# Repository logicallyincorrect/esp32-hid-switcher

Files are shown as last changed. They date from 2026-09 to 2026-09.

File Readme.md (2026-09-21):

# HID Switcher

HID Switcher — one keyboard and mouse, three computers

Use one USB keyboard and mouse with up to three Bluetooth-enabled computers.

Only the selected computer receives input. The other Bluetooth connections stay open. Names, pairings, and shortcuts stay in memory after a restart.

## Hardware

- Freenove ESP32-S3: 16 MB flash and 8 MB PSRAM.
- USB keyboard and relative HID mouse.
- USB hub, if you connect both devices.

Connect the hub to the native USB/OTG port. Use the UART/COM port for power and firmware installation. Use a powered hub if the board cannot supply sufficient power.

A CH340 USB-to-UART port cannot operate as a USB host.

An optional [BLE keyboard/trackpad input experiment](docs/ble-input.md) adds one wireless input peripheral alongside USB, using a separate four-connection build. It is not enabled in the normal firmware.

Printable case files, measured board dimensions, and assembly instructions are in [stls](stls/README.md).

For a print-ready folded handout, use the two-page [A4 quick-start sheet](docs/quick-start-a4.html) (print landscape, duplex, short-edge binding).

## Install or update

Identify the correct board and UART port before installation. Use PlatformIO with [platformio.ini](platformio.ini).

```sh
pio run -e esp32s3_usb_ble_absolute
pio device list
pio run -e esp32s3_usb_ble_absolute -t upload --upload-port YOUR_UART_PORT
```

These commands install the companion-free absolute-pointer build. Use `-e esp32s3_usb_ble` instead for relative-only firmware with optional macOS companion routing. The `esp32s3_usb_ble_absolute_only` environment is a diagnostic fallback, not the full calibration-capable firmware.

All firmware updates use USB. The [browser setup page and serial CLI](docs/usb-setup.md) can configure the device over its UART/programming port, including first-time BLE keyboard pairing without an existing keyboard. The BOOT menu remains available; no Wi-Fi is needed. The existing partition layout remains compatible with saved settings. Do not erase flash unless you want to remove pairings and settings.

## Connect computers

1. Press Ctrl + Cmd + 1.
2. Pair **HID SWITCHER BLE** in the first computer's Bluetooth settings.
3. Press Ctrl + Cmd + 2.
4. Pair the second computer.
5. Repeat for slot 3, if necessary.

Cmd means Command on macOS or Windows/Super on other keyboards. Left and right modifier keys have the same function.

## Switch at the edge of the screen

Both options provide seamless edge switching, **off by default**. Choose the firmware for the behavior you want:

| | Companion-free mode | macOS companion mode |
| --- | --- | --- |
| Firmware environment | `esp32s3_usb_ble_absolute` | `esp32s3_usb_ble` |
| Software on each computer | None | macOS companion on each source Mac |
| Pointer output | Absolute when enabled; relative otherwise | Relative |
| Setup | Enable in menu; calibrate each slot or choose All | Install companion, then enable in menu |
| Screen information | Two-corner calibration, one display per computer | Companion reports desktop edges; shared monitor boundaries stay on the same computer |
| Pointer after switching | Opposite edge, retaining normalized vertical position | Destination pointer stays where it was |
| Mouse controls | Five buttons and vertical scroll in absolute mode | Eight buttons and horizontal/vertical scroll |

Both use slots 1 → 2 → 3 from left to right, skip disconnected computers, and do not wrap at an outer edge. Dragging, held keys and configuration block automatic switching. Keyboard/mouse switching shortcuts work in either mode.

For companion-free mode, select **6 Seamless switching → 1 Enable**. Missing calibration starts the two-corner procedure before switching can turn on. Recalibrate one slot or all connected computers through **6 → 3 Calibrate pointer**. The integrated build works on both tested computers, including absolute dragging. See [calibration instructions and limitations](docs/absolute-pointer.md).

Download the companion ZIP from [Releases](https://github.com/logicallyincorrect/esp32-hid-switcher/releases), or get a development build from [Actions](https://github.com/logicallyincorrect/esp32-hid-switcher/actions/workflows/companion-macos.yml). See [build and installation instructions](companion/README.md).

An optional [macOS companion](companion/README.md) lets you push the pointer against the right edge to select the next computer, or the left edge to select the previous one. Install it on each Mac from which you want to switch at a screen edge. Disconnected computers are skipped. Slots run left to right as 1, 2, 3. Edge switching stops at either end and does not wrap. Switching does not require a companion on the destination. Push outward after reaching an edge to switch input (100 mouse counts by default); the destination pointer stays where it was.

Shared monitor boundaries stay on the same computer. Dragging, held keys, and the setup menu disable edge switching. Keyboard and mouse shortcuts remain available.

The normal build requires the companion, updated firmware, and **6 Seamless switching → 1 Enable**. Hardware validation is pending.

## Configure the device

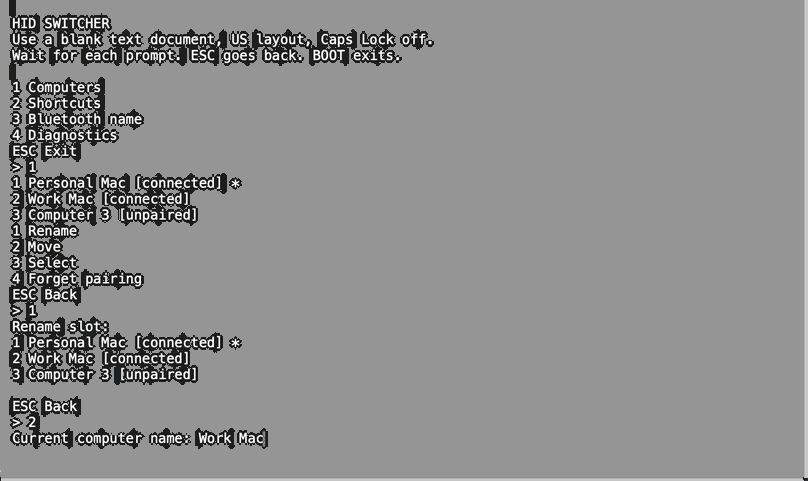
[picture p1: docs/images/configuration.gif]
Streaming device configuration in a text editor


1. Open a blank document in a text editor on the selected computer.
2. Select the US keyboard layout on that computer.
3. Set Caps Lock to off.
4. Hold BOOT for three seconds.
5. Wait for the menu and its `>` prompt.
6. Press a menu number.

The device types the menu into the document. It reads configuration input directly from the attached USB keyboard and mouse. No software installation is necessary.

Use a text editor, not a command shell. Keep the document selected until you exit. The device cannot detect which application receives its text.

| Menu | Function |
| --- | --- |
| Computers | Rename, move, select, or forget a computer |
| Shortcuts | Record, clear, or restore shortcuts |
| Bluetooth name | Change the device name |
| Diagnostics | Show USB status, Bluetooth errors, and report times |
| Edge switching | Set the outward movement distance (1-10000 counts) |
| Seamless switching | Opt in/out; calibrate one slot or All in the absolute build |
| Pointer tuning | Advanced per-computer axis percentages (absolute build) |
| BLE input devices | Scan, select, pair, reconnect, disconnect, or forget a wireless keyboard/trackpad (experimental BLE input build) |

To change the edge distance, select **5 Edge switching**, enter a value, press Enter, then `y`. The value applies immediately and stays saved after restart.

Each configuration menu shows the current settings. Unassigned shortcuts show **Not set**.

Enter names with printable ASCII characters. Press Enter to review a name. Press `y` to save or `n` to cancel. Uppercase `Y` and `N` also work.

Press Escape to go back without saving the current input. Escape at the main menu exits setup. Press BOOT to exit from any screen. The menu also closes after two minutes without input or if its Bluetooth connection is lost. Selecting another computer closes the menu before the switch.

The RGB LED is yellow in configuration mode. Normal keyboard and mouse input stops while the menu is open.

## Shortcuts

| Action | Function | Default | Input device |
| --- | --- | --- | --- |
| Cycle | Next connected computer | Ctrl + Cmd + Tab | Keyboard, mouse, or both |
| Next | Next connected computer | None | Keyboard, mouse, or both |
| Previous | Previous connected computer | None | Keyboard, mouse, or both |
| Slot | Any slot, including disconnected slots | Ctrl + Cmd + 1/2/3 | Keyboard only |

Cycle, Next, and Previous skip disconnected computers and repeat through the slot list. With no other connected computer, selection stays unchanged.

To change a shortcut:

1. Select **Shortcuts** from the menu.
2. Select the action.
3. Select **Record**.
4. Wait for the prompt.
5. Press and release the combination on the attached USB keyboard or mouse.
6. Press `y` to save after the confirmation prompt.

For Slot, record only modifier keys. Use those keys with 1, 2, or 3 to select a slot. Mouse shortcuts can include keyboard modifiers. Wheel and movement gestures are not supported.

**Clear keyboard** and **Clear mouse** remove only the specified input type. Recording one input type keeps the other shortcut. **Restore defaults** resets all shortcuts. Each change requires confirmation.

## Forget a pairing

1. Select **Computers**, then **Forget pairing**.
2. Select the computer's slot.
3. Check the displayed name.
4. Press `y` or `Y` to confirm.

The bridge disconnects that computer and clears its pairing. The slot name, shortcuts, and other pairings stay saved. If you forget the current computer, setup closes when it disconnects. Press Esc or `n` to cancel before removal.

Also forget HID SWITCHER BLE in that computer's Bluetooth settings before pairing again. Select the empty slot to pair a replacement computer.

## Status and recovery

GPIO2 flashes the selected slot number. The RGB LED shows blue/green/purple for slots 1/2/3. A steady light means ready; a flashing light means disconnected.

Initial pairing does not require the menu. Use the default Slot shortcut to select an empty slot. If Bluetooth is unavailable, use UART at 115200 baud: `1`/`2`/`3` selects a slot, `?` shows status, `u` restarts USB devices, and `v` toggles verbose USB diagnostics (off by default).

## Limits and tests

Tested hardware: Moonlander, Logitech MX Master 3S receiver, USB hub, and two Macs. Three simultaneous computers and other operating systems require more tests.

Connect your keyboard and mouse directly or through one USB hub. Hubs cannot be chained together. Keyboards must support sending up to six held keys at once, plus modifier keys such as Ctrl and Shift. Relative mode supports eight mouse buttons and horizontal/vertical scrolling. Absolute mode currently supports five mouse buttons and vertical scrolling.

Media keys, touchscreens, and drawing tablets are not supported. Vendor-specific configuration protocols, including HID++, are not supported yet.

Menu text requires the US keyboard layout and Caps Lock off. Normal input does not have this restriction. Diagnostics do not measure total mouse-to-screen delay.

```sh
sh scripts/test-host.sh
pio run -e esp32s3_usb_ble -e esp32s3_usb_ble_absolute
python3 tests/partition-layout.py
```

Host tests cover menu commands, output flow, shortcuts, and input routing. They do not replace tests with physical devices.

See [architecture](docs/architecture.md), [dependencies](DEPENDENCIES.md), and [planned work](TODO.md).

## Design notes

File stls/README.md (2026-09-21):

# Freenove ESP32-S3 snap-fit case

Printable prototype for the user's measured 16 MB, no-camera Freenove board with soldered headers. Two parts: a base and a lid with integral BOOT/RESET flexures, downward actuator pegs, four releasable short snap catches behind the buttons. Outside dimensions: **38 × 64.95 × 24.9 mm**. All snap teeth are inside this outline.

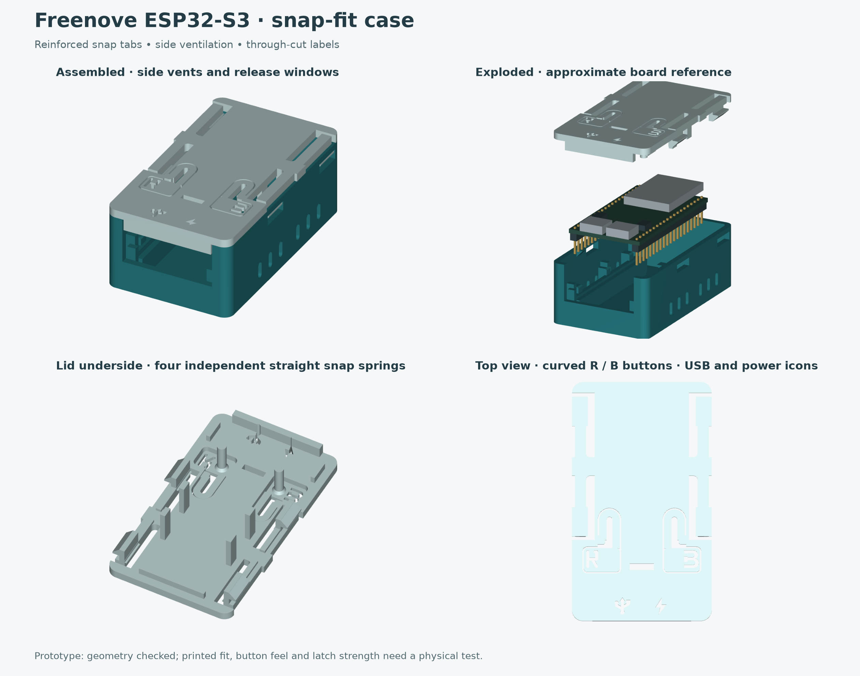
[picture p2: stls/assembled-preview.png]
Assembly and underside


## Ventilation and cut-through labels

Twelve vertical rounded **2 × 5 mm** ventilation slots form matching patterns on the lower side walls, six per side. They remain exposed when a hub covers the lid. The slot bottoms are 3.5 mm above the underside; they do not cut the snap pockets or roots. Thermal performance has not been measured.

**R** and a rounded **B** are straight through-cut stencil letters on the moving button tabs, on the outboard part of each rounded paddle at Y=12.8 mm, clear of the actuator peg roots. The B uses two 0.8 mm bridges across its left stem to retain the centres while preserving its rounded lobes.

A **USB trident** identifies the left native USB/OTG connector; a **lightning bolt** identifies the right UART/power/programming connector, viewed with the USB ports toward you. This mapping follows the UART connection illustration on printed page 28 (PDF page 30) of [Freenove's C tutorial](https://github.com/Freenove/Freenove_ESP32_S3_WROOM_Board_Lite/blob/main/C/C_Tutorial.pdf). Both icons are straight through-cuts over their ports, replacing HUB/PWR text.

There is no raised, bevelled or shallow engraved text. The cutouts stay within the button tabs; the surrounding U slots and peg roots remain intact. Clear strings from the apertures after printing. Letter cutouts change the tabs' stiffness, so button feel and fatigue need a physical check.

## Internal snap-fit revision

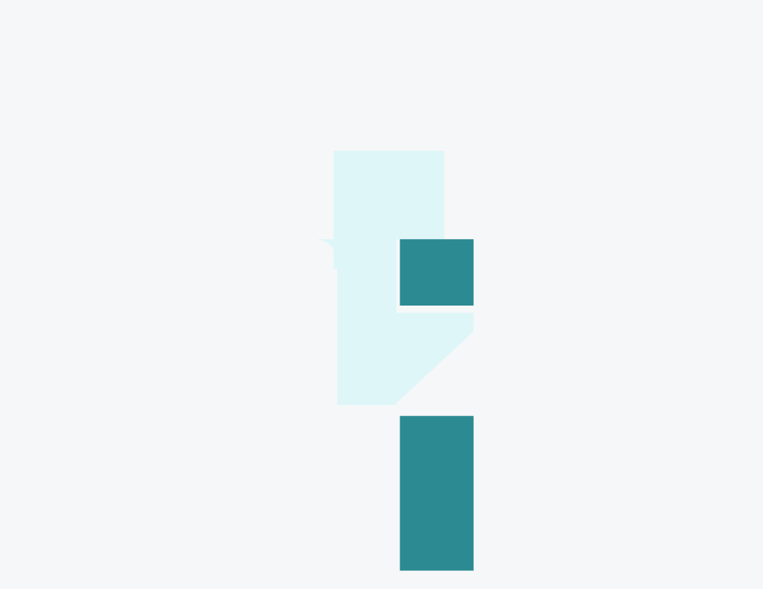
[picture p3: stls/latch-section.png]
Actual latch cross-section: light lid tongue beneath dark base shoulder


The previous tall tongues broke almost immediately in the user's PLA print. They are replaced by **four short, solid internal catches**, two per side at Y=23 and 53 mm: **4.5 mm projection** instead of 10 mm, **8 mm width**, **1.6 mm constant thickness**, and **0.6 mm root fillets**. The teeth overlap the base by **2.0 mm**, increased by 0.5 mm from the preceding version. Flat retaining shoulders sit 0.2 mm below the catch roofs. The teeth now reach the outside wall plane through the existing catch windows.

Each tooth now has its **own straight spring**, two per side, replacing the U-return shape. Each spring is now **3.0 mm wide** (previously 1.6 mm), with a **16.5 mm free length**, **1.2 mm plan-view root fillet**, and a **1.6 mm wide × 0.8 mm deep underside reinforcing rib**. The rib sits inside the base wall and increases the local section depth from 2.4 to 3.2 mm. This revision targets infrequent opening and firmer lid retention, rather than an easy-release feel. Front and rear springs attach independently to rigid roof near the middle of each side. The four teeth extend 0.5 mm farther outward into the existing windows, with 2.4 mm inward relief for 2.2 mm release movement. The R/B button springs retain their curves.

CAD verifies four separate spring attachments and nominal catch clearance, not printed stiffness or fatigue. A temporary root-severing check detaches four separate spring-and-tooth pieces.

**This stiffness revision needs only a new lid.** The base and R/B buttons are unchanged; the snap springs are reinforced and the four teeth extend 0.5 mm farther outward. All zip-tie slots have been removed, leaving solid roof around the spring roots. The base has four **9 × 3 mm** through catch windows near the seam. The rear pair remains at Y=53 mm. Push the teeth inward through these windows while lifting evenly.

Optional `snap-test-base.stl` and `snap-test-lid.stl` are cropped mating sections for checking insertion, tooth return and release before another full print. They preserve the latch geometry and print orientations but do not reproduce complete-case stiffness or hub loads. Do not infer full-case strength from the coupons.

Both header channels and their housing guides move **0.55 mm outward per side** after the latest printed fit showed the channels were 1 mm too close together. Their modelled centre spacing is now **24.5 mm**, increased from 23.4 mm. This uses the latest approximate 24.5 mm measurement, interpreted as row centre-to-centre spacing. Fore-and-aft clearance is now 0.1 mm total (0.05 mm per end), down from 0.3 mm. The end stops extend up to the PCB edges rather than locating only the assumed header-plastic ends. This closer fit needs a physical check; do not force the PCB if print tolerances close the gap. Side locators allow 0.15 mm per side. Tapered guide ribs locate the Dupont plastic housing; the 1.2 mm pin channels leave clearance around the metal contacts. This is a close sliding fit, not an intentional interference fit that bends pins. Header plastic width is still modelled as 2.54 mm.

The prior PLA improvements remain: 1.6 mm bearing rails/end fences, substantial lid hold-down ribs (now 1.5 × 3.2 mm, repositioned for the moved headers), 2.6 mm pegs, rounded slot ends, and 45-degree button-stop ramps in the base. Each button now has a shorter 2.0 mm thick U-return spring with 2.0 mm legs and 2.8 / 0.8 mm outer / inner bend radii. The bend moves forward 4 mm to Y=23.5 mm. The surrounding cutout follows the rounded paddle and rounded spring end with 0.4 mm perimeter clearance, replacing the large rectangular opening, joining a rounded paddle. The side root is rounded and thickened to match. The paddles remain 1.2 mm thick so their stop contact stays unchanged. The peg centres, rest gaps and supported travel stops remain unchanged. Printed fit, button force and repeated latching need another prototype.

## Files

- `base.stl`: print flat bottom down, as exported.
- `lid.stl`: print flat exterior face down, pegs/hooks pointing up, as exported.
- `case.step`: editable assembled case geometry.
- `board-reference.step`: approximate clearance reference, not a printable case part.
- `board.json`, `generate.py`, `preview.py`: measured inputs, parametric CAD and actual-geometry renderer.
- `validation.json`: solid, mesh, assembly, insertion and clearance checks.
- `slicer-validation.json`: Bambu Studio slicing smoke-check result and input hashes.

## Measurements and allowances

User caliper measurements are recorded in `board.json`. X measurements start at the left PCB edge, with USB ports toward the viewer. CAD X=0 is the board centreline. Y=0 is the USB-end PCB edge, not the connector face. See [measurement diagram](measurements.svg).

| Feature | Nominal allowance |
| --- | --- |
| Main PCB location | 0.15 mm each side; 0.05 mm each end |
| Pin tips above floor | 1.15 mm |
| Pin channel | 1.2 mm wide for a measured 0.65 mm pin (0.275 mm clearance per side) |
| Board vertical retention | 0.25 mm above PCB at hold-downs |
| Button peg rest gap | 0.5 mm above unpressed switch |
| Button flexure | Short U-return, 2.0 mm thick, 2.0 mm legs; 1.2 mm paddle |
| Button travel stop | Base wall ramp under outer paddle, 1.2 mm tab travel; switch travel itself is unmeasured |
| Lid locating lips | 0.3 mm from inner wall |
| Snap hooks | 2.0 mm engagement, entry ramp, internal catches and inward release |

A common 27.6 × 10.2 mm opening accommodates both USB connectors and cable overmoulds. Cable overmoulds were not measured; check your actual plugs. USB centres, shell widths/heights and zero protrusion use the supplied measurements. USB shell depth and module footprint remain approximate; overall component height uses the supplied 3 mm maximum (USB shell separately 3.1 mm).

## Printing and assembly

This revision targets PLA. Use your calibrated PLA profile; printed PLA still has limited flexure fatigue life. Suggested starting settings: 0.4 mm nozzle, 0.2 mm layers, 4 walls, 5 top/bottom layers, 20–30% infill. These are prototype settings, not mechanically validated. Preserve the exported orientations and print at 100% scale.

The base cable opening is open at the top, avoiding a long bridge. The button stops are now supported 45-degree base ramps, not lid bridges.  Avoid supports in the button slots. Keep seams off flexure roots and snap ramps where practical.

1. Remove strings and elephant-foot burrs, especially around the button and snap reliefs.
2. Check that the four spring reliefs are free of strings.
3. Drop the board into the base, USB ports at the opening. Header plastic rests on the rails; pins sit in the channels. The header centres are now 24.5 mm apart based on the approximate measurement; do not force the board if it does not seat.
4. Lower the lid squarely and engage all four catches. Confirm both buttons are released at rest and can be pressed individually. Trim pegs slightly if the switches are preloaded; regenerate longer pegs if they cannot reach. Stop if button force rises sharply.
5. Gently move each internal tooth inward about 2.2 mm through its release window, then lift the lid. Lift evenly rather than pulling hard on a single corner.

## Verification

Both STL meshes are watertight, consistently wound, single connected parts on Z=0. The CAD checks found no interference between the assembled case and nominal board envelopes, through the board's vertical insertion path, or at sampled ±0.14 mm X and ±0.04 mm Y board offsets. Retaining-shoulder probes catch after 0.35 mm of upward movement and clear the wall after 2.2 mm inward release. The shoulders also catch with 0.4 mm of simulated engagement loss. These are geometry checks, not a spring simulation. These checks cover the modelled geometry, not unknown components, cable bodies or material deformation.

Bambu Studio 02.08.02.61 successfully sliced both case STLs and both snap-test coupons on one X1 Carbon 0.4 mm plate at 0.2 mm layers, using four walls, 25% infill, five top/bottom layers, supports disabled, and the Generic PLA preset. The CLI returned success with no warnings. This is a slicing smoke check, not a physical bridging/strength test. No printer was contacted. Generated G-code is not distributed; slice for your own printer and filament.

The user physically tested the preceding internal-snap version and reported that the tall teeth broke almost immediately. This revised version has not been physically tested; latch strength, tooth return, closer housing fit remain to be checked.

## Regenerate

```sh
uv venv /tmp/hid-case-cad-venv --python 3.11
uv pip install --python /tmp/hid-case-cad-venv/bin/python -r stls/requirements.txt
/tmp/hid-case-cad-venv/bin/python stls/generate.py
/tmp/hid-case-cad-venv/bin/python stls/preview.py
```

The generator stages its outputs and publishes only after all geometry checks pass. Re-run slicing after any geometry change; `slicer-validation.json` records hashes to identify the exact checked STLs.

## References

User caliper measurements supersede photo estimates. [Manufacturer listing](https://store.freenove.com/products/fnk0099) and [pinout](https://github.com/Freenove/Freenove_ESP32_S3_WROOM_Board_Lite/blob/main/ESP32S3_Lite_Pinout.png) identify the layout. The [user-supplied MakerWorld mockups](https://makerworld.com/en/models/1625563-freenove-esp32-s3-wroom-model-files#profileId-1716334) include the Lite variant; their author adds component and GPIO clearance. The listing was inspected, but its mesh was not imported or redistributed. The approximate board reference here is built independently from measurements and simple envelopes.

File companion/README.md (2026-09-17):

# Edge-switching companion

The optional macOS companion switches computers when you push the pointer against the left or right edge of your desktop. Right selects the next available slot; left selects the previous slot. It skips disconnected computers. Slots run left to right as 1, 2, 3. Edge switching stops at either end and does not wrap. The destination does not need a companion.

Install it on each Mac from which you want to switch at a screen edge. It requires macOS 13 or later, Bluetooth, Accessibility permission, and firmware with the edge service. Pair HID Switcher in macOS Bluetooth settings first. Existing shortcuts and device configuration work without this companion. No Wi-Fi or network listener is used.

## Download

Published [GitHub releases](https://github.com/logicallyincorrect/esp32-hid-switcher/releases) include `HID-Switcher-Companion-macOS.zip` and its SHA-256 checksum after the build succeeds. The ZIP supports Intel and Apple Silicon Macs on macOS 13 or later.

For a development build, open [Actions → macOS companion](https://github.com/logicallyincorrect/esp32-hid-switcher/actions/workflows/companion-macos.yml), select a successful run, and download its artifact. Extract the artifact, then extract the app ZIP inside it. Artifacts expire after 30 days.

## Automated builds

The workflow tests and builds companion changes on pull requests and pushes to `main`. To build manually, open the workflow page, select **Run workflow**, and choose a branch.

Publishing a GitHub release builds that release's tag and attaches the ZIP and checksum. A failed build uploads no release assets. Re-running a successful release workflow replaces those two assets. Tags alone do not create a release.

Builds use an ad-hoc signature. They are not Apple-notarized and require no signing secrets. CI checks tests, both CPU architectures, the extracted app, executable permissions, and signature integrity. It does not test Bluetooth hardware or Gatekeeper approval.

## Open the app

Copy `HID-Switcher-Companion-macOS.zip` to the other Mac and unzip it. Move the complete `HID Switcher Companion.app` to Applications, then double-click it. The app supports Intel and Apple Silicon Macs; do not copy only the executable from inside the bundle. A mouse icon appears in the macOS menu bar. Open its menu, select **Choose device**, and select your HID Switcher. The app remembers your selection. Other connected HID devices can appear in the list.

The menu shows connection status and provides **Allow Accessibility**, **Bluetooth Settings**, and **Quit HID Switcher**. Edge switching requires updated firmware on the board.

## macOS blocks the app

The local build is ad-hoc signed and is not notarized by Apple. ZIP and signature checks do not establish Gatekeeper approval on another Mac.

If macOS reports an unidentified developer or says Apple cannot check the app, use **System Settings → Privacy & Security → Open Anyway** for this app. See [Apple's instructions](https://support.apple.com/en-us/102445). A managed Mac may require IT approval. A generic “cannot be opened” error can have a different cause; check the exact message before changing security settings.

## Build and try

From the repository root:

```sh
sh companion/test.sh
sh companion/build.sh
sh companion/verify-package.sh
"companion/build/HID Switcher Companion.app/Contents/MacOS/hid-switcher-companion" list
```

Copy the UUID for your HID Switcher. The list can also contain other connected keyboards; choose the correct device. Discovery uses service IDs, so renaming the switcher does not prevent discovery.

```sh
"companion/build/HID Switcher Companion.app/Contents/MacOS/hid-switcher-companion" run --device YOUR_UUID
```

Allow Bluetooth when macOS asks. Enable Accessibility for the companion in System Settings. Use `check` to inspect permissions without connecting or moving the pointer. Use `permissions` to open the Accessibility permission prompt. Press Ctrl+C to stop a foreground run.

The companion does not pair devices or change the keyboard layout. If it reports a missing edge service, update the firmware before running it.

## Run at login

```sh
/usr/bin/python3 companion/agent.py install --device YOUR_UUID
/usr/bin/python3 companion/agent.py status
```

This copies the app to `~/Applications/HID Switcher Companion.app` and installs a LaunchAgent for your user. Grant permissions to that installed copy. Logs go to `~/Library/Logs/HID Switcher/companion.log`.

```sh
/usr/bin/python3 companion/agent.py stop
/usr/bin/python3 companion/agent.py start
/usr/bin/python3 companion/agent.py uninstall
```

Uninstall removes the LaunchAgent and retains the app. These commands do not change firmware or saved pairings.

## Behavior

- Move the pointer away from an edge once after connecting or switching to arm the feature.
- Push outward after reaching an edge. The default distance is 100 mouse counts; change it in the device menu under **5 Edge switching** (1-10000 counts, saved across restarts). Stopping does not trigger a switch; reversing or leaving the edge clears the accumulated movement. There is no dwell timer.
- A switch has an 800 ms cooldown. Resting at an edge does not switch.
- Shared monitor boundaries do not switch computers. Exposed left and right desktop edges do.
- The destination pointer stays where it was. No reposition request or acknowledgment is sent.
- Held keys, dragging, and the device setup menu disable switching. Sleep, inactive sessions, missing permissions, and stale companion reports disable the feature as well.

The firmware remains responsible for keyboard and mouse input. The companion sends edge/drag state; it does not send keypresses, screen content, or application names.

This feature requires hardware testing across the participating computers. The host tests cover edge detection and protocol/state behavior; they do not establish end-to-end latency.

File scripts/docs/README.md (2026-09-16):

# README configuration demonstration

The GIF shows a continuous simulated configuration session in TextEdit. `menu-demo.cpp` runs the firmware's `DeviceMenu` with simulated connections and settings. It decodes the menu's HID reports into text. No device is connected or changed.

1. Build and export transcripts from the repository root:

   ```sh
   c++ -std=c++17 -Wall -Wextra -Werror -Isrc scripts/docs/menu-demo.cpp -o /tmp/hid-menu-demo
   /tmp/hid-menu-demo /tmp/hid-demo/transcripts
   ```

2. Open a new plain-text document in TextEdit. Use a monospace font. Do not use a document with existing work. Enable Accessibility and Screen Recording for Orca Computer Use.
3. Find the document with `orca computer list-windows --app com.apple.TextEdit --json`.
4. Capture the simulated steps. This clears the specified window once, then appends text in small chunks:

   ```sh
   python3 scripts/docs/capture-textedit.py /tmp/hid-demo --window-id WINDOW_ID
   ```

5. Encode the screenshots. Install Pillow in your Python environment first:

   ```sh
   python3 scripts/docs/encode-gifs.py /tmp/hid-demo/manifest.json docs/images
   ```

Check every frame before publication. The demonstration echoes selection keys and Esc so viewers can follow input without captions. This echo is added by the demo backend; the firmware menu does not echo those keys. The GIF crops out the editor title bar and scrollbars. Menu output appends continuously at a simulated 32 ms per character. Name entry uses 100 ms per character. Captures group up to four characters per frame. These timings do not measure device latency.

`docs/images/header.svg` and `logo.svg` are editable vector artwork. The header includes the logo. No font or image download is required to display them.

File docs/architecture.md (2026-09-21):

# Architecture

`main.cpp` owns one `Application` for the firmware lifetime. Arduino calls its startup and tick functions.

| Component | Responsibility |
| --- | --- |
| Application | Input queue, physical input state, shortcuts, menu, LEDs, UART |
| UsbHost | Native USB startup, HID interfaces, mouse decoding, USB recovery |
| BleHid | BLE peers, saved configuration, input submission, connection recovery |
| MenuBackend | Connect the text menu to application services |
| DeviceMenu, TextConsole | Menu state and paced text output |
| InputState, UsbMice | Release barriers and mouse button state |
| MultiHostRouter, pending queues, MouseCadence | Selected-host routing and bounded input scheduling |
| EdgeSwitch | Fresh companion state, cooldown, and immediate switching |
| AbsolutePointer, PointerTuning | Per-slot absolute position, calibrated axis scaling and companion-free switching |
| PointerCalibration, CalibrationFeedback | Two-corner captures, origin-host results and configuration return |
| macOS companion | Desktop edges and sleep state |
| Board | Pins, serial speed, and default identity |

## Task boundaries

The application loop owns settings, BLE routing, and the menu. BLE callbacks copy events into a bounded queue. USB callbacks copy input into a separate bounded queue. Callbacks do not write settings or run the menu.

The USB host task services the controller and executes root-port recovery after event dispatch; the application loop only requests recovery. The HID driver task receives reports. A connection worker opens interfaces and reads descriptors. A short lock protects USB interface and mouse state. No driver call, output callback, or serial write runs under that lock.

Startup retains a one-second settling interval before USB installation. An interface-open failure is reported without resetting the bus: an optional interface can exceed the controller channel limit while keyboard and mouse input remain active. Transfer failures still use the bounded recovery policy.

USB callbacks close detached interfaces. The driver owns handle storage; application input queues contain copied reports, not driver pointers. Diagnostics use snapshots and do not register temporary USB clients.

## Input rules

Drain USB input before each BLE submission pass. Preserve keyboard transitions. Accumulate relative mouse movement with the existing bounded queues and negotiated pacing.

Only the selected host receives normal input. Switching releases held input. Menu transitions suppress held shortcut keys and mouse buttons until release. Queue overflow and USB recovery require release even when the last physical state is unknown.

## Persistence and compatibility

Preserve existing NVS namespaces, partition offsets and bonded identities. Version new settings records and HID layouts explicitly; request GATT Service Changed when a report map or service layout changes, without erasing pairings or calibration. Renaming a source file must not require pairing again. Pairing removal uses a saved pending marker so startup can complete an interrupted removal.

## Changes and validation

Put platform-independent behavior in small state types with host tests. Inject service references into adapters. Keep queues bounded and report callbacks short. Do not add sleeps or allocation to the normal report path.

Run `sh scripts/test-host.sh`, `pio run -e esp32s3_usb_ble -e esp32s3_usb_ble_absolute`, and `python3 tests/partition-layout.py`. Hardware tests must also cover reconnect, setup, switching, and simultaneous keyboard/mouse input. Host tests and controller timing do not prove mouse-to-screen latency.

## Edge switching

The optional encrypted BLE edge service receives bounded samples through the existing event queue. `EdgeSwitch` runs only in the application loop. The companion never selects a slot directly: Accumulated outward USB motion at the configured distance (default 100 counts) at the reported edge triggers switching, without a dwell timer. Reversing or leaving the edge clears the accumulation. Only the source needs a companion; the destination needs a ready HID connection. The destination pointer is not repositioned. Samples carry an epoch and expire after 600 ms. Reconnection, configuration, and selection changes invalidate them.

The application checks held input and menu state before committing a handoff. Companion traffic is bounded to one write in flight and periodic heartbeats; it does not replace the HID data path. See [protocol](../companion/PROTOCOL.md).

The edge distance is one NVS unsigned integer (`edge-distance`) in the existing settings namespace. Values outside 1-10000 are rejected. A save must succeed before the runtime threshold changes; updating it clears pending edge motion. Missing or invalid stored values use 100.

## Companion-free absolute pointer

The absolute build exposes two HID services with independent report maps. The primary service contains keyboard report 1 and six-byte absolute mouse report 2 (five buttons, X/Y and vertical wheel). The second service contains relative report 3 for calibration and seamless-off movement. Device Information is shared. Normal gestures use exactly one mouse path; absolute clicks, drags and wheel events are never mirrored onto the relative service. This replaces the combined mouse map that caused macOS to release held clicks during absolute movement.

Seamless switching is opt-in and requires calibrated connected slots. Calibration measures raw movement while sending relative output, suppresses marking clicks, persists per-bonded-host spans, and returns to the origin host for feedback and the normal menu. The primary absolute report uses the NanoKVM-style descriptor validated on both user computers. See [calibration and transport details](absolute-pointer.md) for limitations and the diagnostic fallback.

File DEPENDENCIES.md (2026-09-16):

# Dependencies

- [ESP32_USB_Host_HID](https://github.com/esp32beans/ESP32_USB_Host_HID): vendored USB HID driver. Its [license](lib/ESP32_USB_Host_HID/LICENSE) and [local change record](lib/ESP32_USB_Host_HID/LOCAL-CHANGES.md) remain with the source.
- [NimBLE-Arduino](https://github.com/h2zero/NimBLE-Arduino): BLE stack and HID service.
- [ArduinoJson](https://github.com/bblanchon/ArduinoJson): structured configuration commands and diagnostics.
- Espressif Arduino core and ESP-IDF, supplied by the pinned pioarduino platform: board runtime, USB host controller, storage, and radio support.

Dependency versions and board settings are in `platformio.ini`. Each dependency retains its own license.

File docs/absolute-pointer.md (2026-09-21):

# Companion-free absolute pointer and monitor arrangement (experimental)

The absolute-pointer firmware now starts with **seamless switching OFF**. It forwards normal relative mouse movement until you explicitly enable seamless switching. Optional calibration and automatic edge switching target **one display per computer**, in slot order 1, 2, 3.

Build without flashing:

```sh
pio run -e esp32s3_usb_ble_absolute
```

The binary is `.pio/build/esp32s3_usb_ble_absolute/firmware.bin`. The normal `esp32s3_usb_ble` build retains relative mouse output and optional companion routing. Both builds require explicit opt-in for seamless switching and preserve existing pairing/slot settings. The companion build uses companion position feedback and does not require this absolute-pointer calibration.

## Enable seamless switching

Open a blank text document on the selected computer, use a US keyboard layout with Caps Lock off, and hold BOOT for three seconds. Choose **6 Seamless switching → 1 Enable**.

Enable takes effect immediately and survives reboot. Calibration is optional; no connected slot needs a corner-to-corner sweep before it can participate.

All connected, subscribed computers can participate without calibration. Keyboard/mouse switching shortcuts remain available outside calibration.

To disable, use **6 Seamless switching → 2 Disable**. Mouse movement returns to relative output.

## Calibrate one slot or all

Choose **6 Seamless switching → 3 Optional sensitivity calibration**. Select slot **1**, **2**, **3**, or **4 All ready computers**. All snapshots the connected, calibration-ready slots and visits them in ascending order. It does not discover multiple monitors attached to a single computer.

Keep the original text document focused on the computer where you started setup. The instructions finish there before any slot change. On each selected computer:

1. Move the cursor to the **top-left corner**, then left-click and release.
2. Wait for the LED to show **two cyan flashes**.
3. Move smoothly to the **bottom-right corner**, then left-click and release. Stop at the corner instead of continuing to push against the edge.
4. The switch returns to the original computer and types **“Slot N calibration OK.”** It types the next slot's instructions there, completes the final key release, then switches to that slot.
5. At the end it stays on the original computer and types **“Calibration complete.”** If calibration was started by Enable, it also reports whether seamless switching was enabled successfully. After the final message finishes, the normal configuration menu reappears on that computer. ESC or BOOT exits setup as usual.

The LED shows one cyan flash for top-left and two for bottom-right. Green after the flow means captures completed; amber means cancellation; red means failure. While results are being typed, it stays green. ESC or BOOT cancels and returns to the original slot. Normal keyboard input, mouse buttons, scrolling, shortcuts and automatic edge switching are suppressed during calibration; marking clicks never reach an application.

There is a two-minute inactivity limit per capture. Disconnects, stale input, transport/session changes and invalid spans abort the active capture. Completed slots stay saved if a later slot fails or the flow is cancelled; an unfinished/invalid slot keeps its old settings. Slots that disconnect before their turn are skipped and listed in the final message. If the original host disconnects during feedback, output stops rather than typing the result on another host.

## What the measurement means

During calibration, the firmware sends a separate **relative mouse report**, so each host moves the cursor using its normal relative-pointer behavior. It counts raw X/Y movement between the two human-marked corners, then maps those spans to the absolute range 0–32767. Measuring while using the old absolute gains would merely reproduce those gains and could not correct the ultrawide problem.

No resolution or DPI entry is required. This is an empirical calibration at the speed of your sweep, not an automatic display-resolution measurement. Host acceleration, changing mouse DPI, overshooting the edges, other pointing devices, or different host pointer settings can affect the result. Move at a normal, steady speed and repeat calibration after display or mouse-setting changes. It cannot reproduce the host's full acceleration curve at every speed or guarantee identical physical speed across machines with different settings.

Recorded spans follow the bonded computer when slots are reordered. Completing optional calibration estimates **one shared sensitivity** from configured dimensions divided by measured spans, averaging both axes and the slots completed in that run. It applies only at the end; cancelling leaves sensitivity unchanged. This is an approximate fit at the sweep speed, not a copy of the OS acceleration curve. Confirm dimensions first for a meaningful pixel-based estimate.

The webpage and **7 Pointer tuning** set shared sensitivity (1–1600%). At 100%, one raw mouse count advances one configured desktop pixel on either axis. Each slot converts that travel into absolute HID units: `delta × 32767 × sensitivity / (100 × configured axis dimension)`. Fractional scaling retains small movements. Calibration spans and old per-slot percentages no longer determine normal motion. Changing monitor dimensions now changes movement scaling as well as edge geometry; OS-side behavior can still influence observed cursor motion. Scrolling is unchanged.

## Edge behavior

After opt-in, firmware owns the absolute cursor position. At edge distance 1, reaching the left/right boundary switches immediately. Higher settings require pushing beyond the boundary by the distance configured under **5 Edge switching** (default 100 raw counts). Connected slots are searched in that direction without wrapping. Entry is at the opposite edge with the same normalized Y.

Dragging, held keys, the setup menu and calibration block edge switching. An 80 ms guard prevents an immediate return across the entry edge; continued travel toward the next screen is not delayed. Companion routing does not drive the absolute-pointer build. Cursor movements made by another mouse, trackpad or an application cannot be observed; the next absolute report can jump back to the firmware's position.

## HID transport and compatibility

The primary HID service contains keyboard report 1 and the NanoKVM-style absolute mouse report 2. The mouse carries five buttons, 16-bit absolute X/Y with logical and physical ranges 0–32767, and vertical wheel in one six-byte report. Press, drag, release, and scrolling all stay on that device. Neutral releases retain the last position.

A second HID service contains only relative report 3 (eight buttons, signed 16-bit X/Y, wheel and horizontal pan). It is used during calibration and when seamless switching is disabled. Its report map is separate so the host does not merge its relative axes with the absolute device's buttons. There is one shared Device Information service. Firmware requests GATT Service Changed on migration (descriptor revision 8), retaining bonds and saved calibration. Calibration requires both services' reports to be subscribed; missing input is never treated as success.

Absolute mode currently supports five mouse buttons and vertical scrolling; horizontal pan and buttons 6–8 remain available in relative mode only. The absolute descriptor matches NanoKVM's `hid.GS2` layout, with a report ID added for BLE. Reference: https://github.com/sipeed/NanoKVM/blob/bd070b2f5ce27d22618e8a1c8d2bdca543429882/kvmapp/system/init.d/S03usbdev

## Validation and diagnostic fallback

The user confirmed the isolated absolute mouse works on both computers. A macOS trace also confirmed sustained leftMouseDragged events with the button held and release only when the raw report released it. The earlier combined absolute/relative report map generated unwanted button releases; a puck descriptor experiment lost cursor movement on one Mac. Those implementations are no longer used.

The two-service integration restores calibration without mixing the two mouse layouts in one report map. Host tests verify descriptor separation, report widths/ranges, calibration state transitions, feedback routing and menu return. On the integrated build, macOS enumerated two independent HID devices: five absolute buttons with no RelativePointer group, and eight relative buttons on report 3. A fresh trace confirmed held drag events and matching release with both services present. The user subsequently confirmed that the integrated build works on both computers. This is device-specific acceptance, not validation of all operating systems or long-term reconnect stability.

`pio run -e esp32s3_usb_ble_absolute_only` retains the validated diagnostic fallback: the same absolute mouse without the relative HID service. It keeps existing calibration and pairings, but cannot recalibrate and always outputs absolute movement even with automatic edge switching disabled. The full calibration-capable mode is `esp32s3_usb_ble_absolute`.

## Monitor arrangement in USB setup

The web setup page has an optional monitor arrangement for absolute seamless switching. Each paired or connected slot appears as one monitor tile. Drag tiles into place (nearby edges snap); the slot number and name stay attached to the tile. Click the pencil beside the resolution or speed to edit it inline, then click the checkmark to save. There are no manual position fields: the tile arrangement is the position editor, and saved positions are persisted on the board. Disconnected slots are omitted from active routing while their saved geometry remains available for when they reconnect.

First-time calibration supplies raw mouse-travel spans, **not display resolutions**. It provides the initial size estimate for each connected slot. Confirm the actual width and height inline when you know them; calibration does not overwrite saved dimensions or positions. Calibration is optional, but it is required before enabling companion-free seamless switching when a slot has no usable calibration. Only paired or connected slots participate in the active arrangement.

In a saved custom arrangement, switching works on touching left, right, top and bottom edges. The crossing point maps through the desktop pixel coordinates, accounting for different dimensions and offsets. Only overlapping edge segments connect; gaps, corner-only contact, uncovered portions and offline neighbours do not switch. Overlapping rectangles are rejected. The destination starts at its matching edge. Drag and held-key protections and the short return guard remain in effect.

The arrangement is attached to slot positions: reassigning computers between slots changes which computer occupies that rectangle. It does not change the shared sensitivity setting, the operating system's display arrangement, or discover monitor resolution automatically. BOOT menu/CLI slot switching and the companion's relative-mode routing remain available; this custom geometry applies only to firmware-owned absolute mode.

## macOS tracking experiment

`scripts/mac-pointer-observer.c` reads the OS cursor location and the live `HIDMouseAcceleration` parameter. Compile with `clang -Wno-deprecated-declarations scripts/mac-pointer-observer.c -framework ApplicationServices -framework IOKit -o /tmp/mac-pointer-observer`.

With the current Mac selected, seamless enabled, web setup disconnected, and the user ready to leave the mouse still, run `scripts/measure-macos-pointer.py --port PORT --observer /tmp/mac-pointer-observer --output artifacts/macos-absolute-tracking.json`. It replays identical absolute coordinates at low, high, and original HID tracking values, records cursor endpoints, and restores the original tracking value and firmware cursor position in a finally block. The test covers that HID parameter and descriptor on the attached Mac; it does not establish how every macOS per-device setting or acceleration curve behaves. Do not run during normal mouse use.

### Observed result on the attached Mac (2026-09-21)

The seven-position absolute-HID replay landed at identical CoreGraphics desktop coordinates for `HIDMouseAcceleration` values 0.0, 3.0, and the original 0.6875. Maximum low/high endpoint difference was 0.0 desktop points. The setter and getter succeeded and the original value was restored. The receipt is `artifacts/macos-absolute-tracking.json` (local generated artifact). This supports using firmware sensitivity for this absolute descriptor on this Mac. It is not a test of all per-device settings, OS versions, or physical mouse acceleration curves.

Screen resolution is edited inside the arrangement: click the pencil beside a screen's dimensions, enter width and height, and choose Done. Drag screens to position them, then save the arrangement. Calibration supplies estimated starting proportions for an unsaved arrangement; it does not measure pixel resolution or replace saved dimensions. Arrange in a row resets visual positions.

The selected screen's speed adjustment remains visible (25–400%, default 100%). Effective speed is shared speed × screen percentage / 100 on both axes; geometry and edge alignment stay unchanged. Existing arrangements migrate with all adjustments at 100%. Calibration and edge travel remain directly accessible.

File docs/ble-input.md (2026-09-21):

# Experimental BLE keyboard and pointer input

This build lets the ESP32 act as a BLE central for **one selected keyboard or keyboard/trackpad**, while remaining a BLE HID peripheral to the existing three computer slots. USB input remains available. Decoded BLE input uses the same shortcuts, configuration menu, release barriers, and selected-slot forwarding as USB input.

It is a separate experiment. The validated USB firmware does not scan for or connect to BLE input devices. No automatic pairing, background scanning, or bond-store eviction is added. An Android nRF Connect boot-keyboard simulation has been physically verified through encryption, HID discovery, notifications, and forwarding. Real keyboard, trackpad, reconnect stability, and four-link timing validation remain pending.

## Build and install

```sh
pio run -e esp32s3_ble_input
pio device list
pio run -e esp32s3_ble_input -t upload --upload-port YOUR_UART_PORT
pio device monitor --port YOUR_UART_PORT --baud 115200
```

Use the board's UART/programming port. The experiment inherits the calibration-capable absolute-pointer firmware. Its separate SDK configuration reserves **four BLE connections**: three computers plus one input peripheral. Computer slots, existing pairings and pointer calibration are retained. Controller diagnostics also account for four links.

To restore the validated USB-input firmware, flash `esp32s3_usb_ble_absolute`; do not erase flash.

## Connect your input device

For setup without a wired keyboard, use the [browser setup page or serial CLI](usb-setup.md). The page scans, pairs, and displays passkeys over USB serial. The BOOT-menu flow below remains available.

Put the keyboard in **Bluetooth pairing mode**, not its proprietary 2.4 GHz dongle mode. Use a USB keyboard for initial setup:

1. Open a blank text document on the selected computer, using US layout with Caps Lock off. Hold BOOT to open configuration.
2. Choose **8 BLE input devices → 1 Scan and add**. The 12-second scan lists nearby BLE HID devices by name and address suffix.
3. Press the number of your keyboard. Selection starts connection and pairing; scanning alone never pairs.
4. If a passkey appears in the document, type those six digits on the **wireless keyboard** and press Enter.
5. Wait for the connected result and return to the configuration flow. Exit with BOOT, then test typing, releases, switching, and the trackpad if supported.

The same menu offers reconnect, disconnect, and confirmation before forgetting the input pairing. ESC cancels a pending scan/pairing operation and returns; BOOT exits. Losing the original computer/configuration session cancels a pending operation so prompts are not typed onto another computer.

Pairing prompts are also printed over UART. Display-with-confirmation IO is enabled while securing the input keyboard, then restored to no-input/no-output for destination-computer pairing. Finish input pairing before pairing computers; already bonded computers reuse their existing keys. Peer-display passkey entry is not supported.

If the peer supports Secure Connections numeric comparison (for example a phone simulating a keyboard), compare the six-digit code on both devices. Only if they match, confirm on the peer and click **Codes match** in web setup, press **Y** at the board menu prompt, or send `b confirm XXXXXX` over UART. The firmware accepts only the pending code, once; cancel or disconnect clears it. Use **Cancel operation** for mismatched codes. A normal keyboard can still request that you type a code on it and press Enter. Web setup and the board menu bind confirmation to the displayed pairing attempt; stale prompts cannot confirm a later attempt. N or ESC rejects the board prompt, and BOOT cancels and exits.

On security failure, the final status retains `pairing=display passkey`, `enter passkey`, `compare passkey`, or `no callback`. This records which input-client callback ran, even if a quick failure replaced its prompt before the webpage polled. `no callback` alone does not establish which security method was negotiated. Include this result and the peer's log when diagnosing pairing; the numeric security error and connection-parameter errors are separate evidence.

Input security starts asynchronously and waits up to 30 seconds for encryption, observing encryption-change errors for the input connection only. MTU and identity events cannot complete this wait. Cancellation and disconnect stop it; discovery and forwarding require an encrypted link. This avoids NimBLE 2.5.1's shared blocking waiter being released by unrelated GAP events.

UART commands remain available for diagnostics; send each with a newline. `b status` shows readiness and decoded/unsupported report counts without logging keys or report contents.

Commands:

| Command | Behavior |
| --- | --- |
| `b scan` | List nearby advertising BLE HID devices; disconnect the current input first |
| `b scan all` | List up to 32 connectable BLE devices regardless of advertised type; also available as Scan all BLE devices in web setup |
| `b connect N` | Connect the selected scan result |
| `b reconnect` | Connect the saved input identity; wake the device first |
| `b disconnect` | Release held input and disconnect the input peripheral |
| `b forget` | Remove only the saved input peripheral's bond and target |
| `b status` | Show input link/readiness/report counters |

There is no automatic reconnect in this first experiment. Use **Reconnect saved device** (or `b reconnect`) after a reboot or input disconnect. If the address changed and reconnect fails, put the device into pairing mode and scan again. Forget an old input before replacing it with another. A full bond store causes new input pairing to be rejected; existing bonds are not evicted.

If a phone simulator or keyboard is absent from the normal HID scan, use **Scan all BLE devices**. The scan retains up to 96 advertisements and reports advertisement, connectable, and displayed counts, with a warning if a limit is reached. Non-connectable advertisers cannot be selected. Broad scanning does not pair automatically or bypass encryption or HID report validation. The BOOT menu offers **5 Scan all BLE devices**, with nine choices per page and N/P for next/previous. The ordinary HID scan remains limited to nine choices.

## Supported reports and limits

- Keyboard usage-page key arrays and one-bit NKRO bitmaps, converted to the bridge's existing six-key-plus-modifiers output. More than six simultaneous non-modifier keys produces HID rollover rather than silently dropping held keys.
- Relative mouse X/Y, buttons, vertical wheel and horizontal pan under a Mouse collection. The existing absolute switching mode can then transform this relative motion using per-slot calibration.
- Boot keyboard/mouse fallback when a device exposes those characteristics and supports switching to Boot Protocol.
- Up to two HID services and eight input-report endpoints on the selected peripheral. HOGP report-reference IDs select the descriptor layout; the ID is not assumed to be a byte in the notification payload.

A combined keyboard/trackpad can work as both devices when it exposes compatible reports. Native multitouch/digitizer contacts, gestures, consumer/media keys, vendor protocols, keyboard LED output, and Bluetooth Classic are not forwarded. A supported keyboard can still work when the trackpad's layout is unsupported. Absolute output retains the existing five-button/vertical-wheel limitation; relative output supports eight buttons and horizontal pan.

USB and BLE keyboard states are merged without one source releasing another source's held keys. Mouse button state is likewise retained per source. Disconnect clears BLE-owned state and releases the destination; held USB input must be released before forwarding resumes. Queue overflow retains the existing release barrier and clears BLE state when a BLE event cannot be queued.

Discovery, connecting, encryption and subscriptions run on a worker task, outside the forwarding loop. Radio airtime is still shared: scanning, pairing and a fourth connection may affect latency. Build and host-test success are not evidence of acceptable physical latency or a particular trackpad's compatibility.

Reference: the pinned [NimBLE-Arduino client example](https://github.com/h2zero/NimBLE-Arduino/blob/2.5.1/examples/NimBLE_Client/NimBLE_Client.ino) and the local 2.5.1 client/security APIs.

## Pairing and management UI

The Input Devices section shows USB devices and the current/saved BLE input name, connection state, and selected destination computer. Add BLE device opens a dedicated dialog; closing it cancels only pending setup. It enables reconnect only for a saved disconnected input, disconnect only for a ready input, and forget only when an input is saved. Disconnect before scanning for another device. Saved input names are retained across reboot; older records display a generic saved-input label until the next successful connection. Only one input target is saved. Reconnection is manual in this version.

Pairing prompts have a dedicated code panel and remaining time. Code entry on the wireless keyboard and numeric comparison have different instructions; numeric comparison uses a single confirmation button. Completed or failed prompts move to Last pairing prompt instead of disappearing. Diagnostic failure codes remain visible in the result.

On-board acceptance checklist (requires a USB keyboard and a connected destination): hold BOOT to enter the menu in a blank US-layout document; choose 8, scan/select the input, follow its pairing prompt, then press BOOT to exit and verify ordinary typing. Repeat cancellation with ESC, rejection with N, reconnect/disconnect, and the Forget confirmation. Automated menu tests cover these control paths, pagination, stale confirmation, host-session loss, and input pass-through after exit; they do not establish physical on-board acceptance.

Discovery merges raw advertising and scan-response packets by address and address type. A scan response arriving first does not permanently mark the device non-connectable, and later advertising packets do not erase a learned name or HID identity. Scans run for 12 seconds with a 60 ms listening window per 80 ms interval; duplicate reports remain enabled for updates. This increases discovery opportunities but shares radio time with computer links.

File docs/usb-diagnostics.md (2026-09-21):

# USB stability work — 2026-09-19

## Current device state

The latest application is flashed and the user confirms keyboard and mouse work.
The final capture contains both keyboard and mouse reports with no USB transfer
errors or BLE transmit failures. Pairings/settings, bootloader, partition table
and OTA metadata were not overwritten. Verbose USB logging is off by default;
UART `v` toggles it for diagnosis.

**Physical hub replug remains unresolved.** Further resets, flashes and physical
reconnect tests are deferred while the user works. Do not describe startup
success or software recovery as proof that physical reconnect is fixed.

## Changes installed

- A build-local patch to the pinned ESP-IDF 5.5.5 root-hub source handles a missing
  root device record during disconnect instead of aborting. The original SDK
  package and its archives are not modified.
- A second patch returns a pending-event power-off error and restores the prior
  root state, instead of asserting that every power-off command succeeds.
- Port power operations now run in the USB event task after event dispatch.
  Rejected commands retry after further dispatch; power-on waits for device
  cleanup and the minimum off interval.
- Only successfully started HID interfaces occupy application tracking entries;
  failed optional interfaces no longer leave stale handles after reconnect.
- The HID driver allocates its transfer before claiming the interface and frees
  it on a failed claim. Allocation failure cannot leak a claimed interface.
- Status exposes host-device count separately from task liveness. `healthy`
  still represents task/recovery health, not proof of working input.

The SDK patches fail closed if their source anchors change; compilation also
checks the pinned SDK version. `src/UsbHub.c` links the corrected root-hub object
in place of the archive's original object. The link map was checked.

## Evidence and limits

The host regression suite and firmware builds pass. Regression tests execute
actual recovery helpers and the HID open function with missing nodes, pending
port events, delayed cleanup, allocation failure and repeated claim failure.

The earlier revision passed four on-board software recoveries with normal
logging, including the formerly crashing recovery immediately after startup:
one boot, four active interfaces after each recovery, no USB transfer errors or
event drops. These results do **not** cover the final revision's second
power-off race fix or physical replug reliability.

The subsequent physical test disconnected cleanly, but replug then repeatedly
failed `SET_FEATURE(PORT_POWER)` on hub port 1. Turning verbose logging on at
runtime did not clear that failure. Manually recovering in that failed state
exposed the second SDK power-off assertion, which prompted the event-task/retry
changes above. Those changes have passed host tests and live startup/input,
but the failed physical-replug state has not yet been retested with them.

Observed devices: VIA hub `2109:2813`, Logitech receiver `046d:c548`, Moonlander
`3297:1969`. The user confirms only keyboard and receiver are attached. The SDK
also reports a connection on hub port 4; its origin is unconfirmed. Do not infer
another user-connected peripheral from that event. Optional HID interfaces and
that connection hit controller allocation limits, while active input interfaces
remain usable. Capacity errors are distinct from the earlier port-power failure.

Ignored local captures and the installed application hash are in
`artifacts/usb-diagnostics/`. Next hardware check, when interruption is acceptable:
capture physical replug on the current build, then test the serialized recovery
against any reproduced port-power failure. No unverified delay or automatic
reset loop has been added to mask the failure.

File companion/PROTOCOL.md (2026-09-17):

# Edge protocol v1

Service: `e963a000-8f4d-4a7b-9b65-62485c81a320`.

Sample characteristic: `e963a001-8f4d-4a7b-9b65-62485c81a320`, write with response on an encrypted, bonded connection.

Status characteristic: `e963a002-8f4d-4a7b-9b65-62485c81a320`, notifications sent only to the authenticated peer. Subscribe before sending samples. No pairing credentials or persistent settings are exposed.

Each message is 12 bytes. Integers use little-endian byte order. Reserved bytes must be zero.

| Offset | Sample: companion to firmware | Status: firmware to companion |
| --- | --- | --- |
| 0 | Version: 1 | Version: 1 |
| 1 | Edge: 0 none, 1 left, 2 right | Recipient slot: 0–2 |
| 2 | Bit 0 dragging, bit 1 enabled | Selected slot: 0–2 |
| 3 | Reserved | Unused; zero |
| 4–5 | Unused; older clients may send height | Unused; zero |
| 6–9 | Last received epoch | Current epoch |
| 10 | Reserved | Unused; zero |
| 11 | Reserved | Reserved |

Firmware authenticates the connection identity; clients cannot claim another slot. Samples expire after 600 ms. The companion sends on edge/drag transitions and at least every 200 ms, with at most one write in flight. Firmware sends status on epoch changes and every 500 ms while subscribed.

Accumulating the configured outward movement distance (default 100 USB mouse counts) at the reported edge switches to the next or previous ready HID connection. Slots are ordered 1, 2, 3 from left to right. Disconnected slots are skipped within that direction; selection never wraps. Only the source needs fresh companion samples. Reversing or leaving the edge clears the accumulated movement. Elapsed time alone cannot trigger a switch. There is no dwell timer, reposition request, or acknowledgment. The 800 ms cooldown and interior-sample rearming prevent repeated switching. The 12-byte v1 layout is retained; old clients can still report edges, but firmware never requests pointer placement. The companion ignores legacy placement fields.

Menu entry, held-input inhibition, changes to ready hosts, disconnects, settings changes, and selection changes invalidate edge state. After invalidation, an interior sample is required before another edge push. A missing source companion or permission disables edge detection on that computer; manual shortcuts remain available.

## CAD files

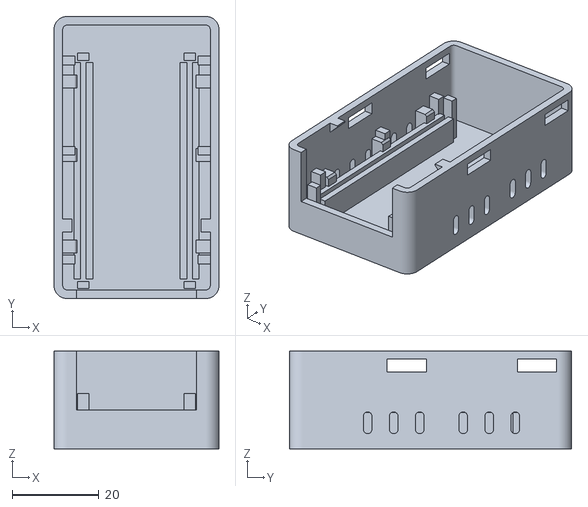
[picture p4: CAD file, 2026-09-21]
stls/base.stl
38.0 x 65.0 x 22.5

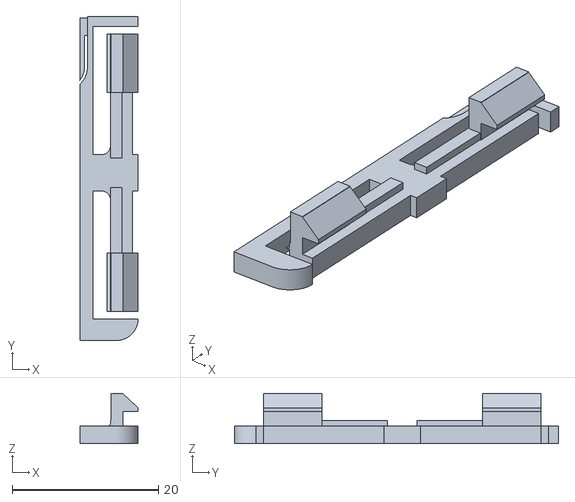
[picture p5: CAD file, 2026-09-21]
stls/snap-test-lid.stl
8.00 x 44.4 x 6.90

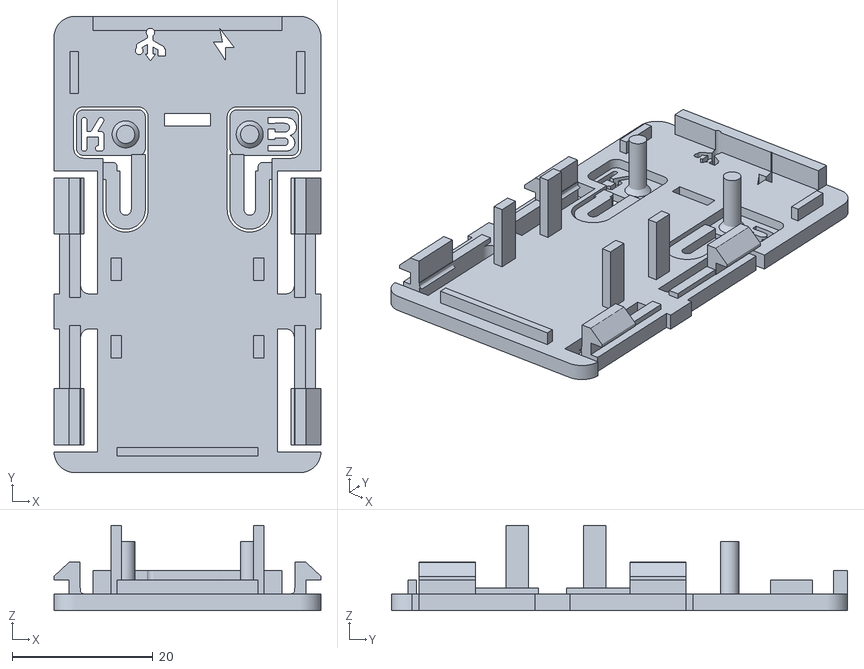
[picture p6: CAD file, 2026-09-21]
stls/lid.stl
38.0 x 65.0 x 12.1

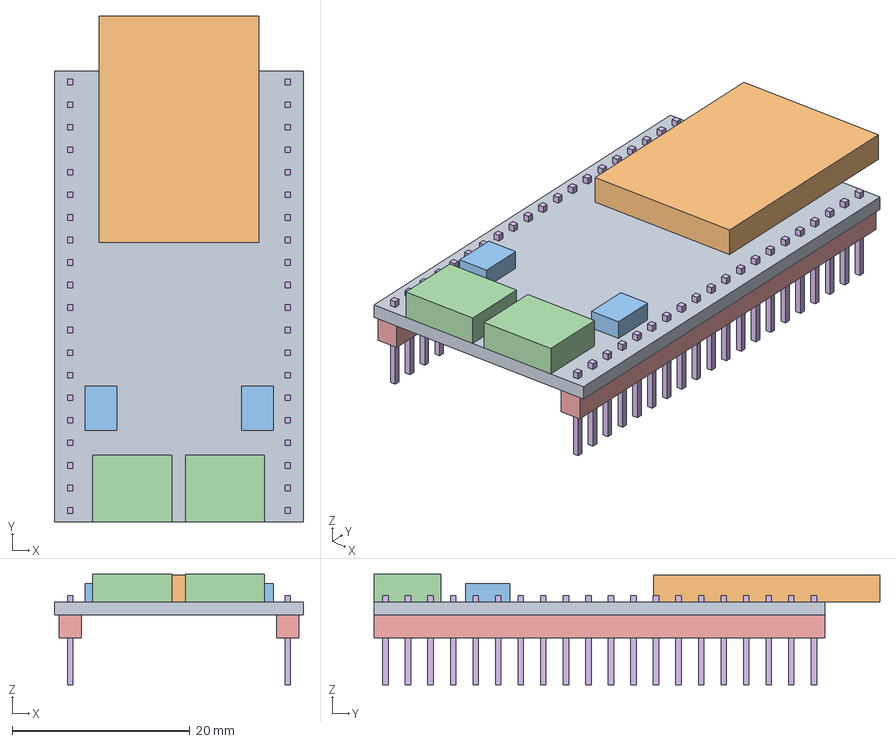
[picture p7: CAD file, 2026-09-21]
stls/board-reference.step
28.1 x 57.0 x 12.4 mm
pcb
module
reset
usb_reset
header_reset
pins_reset
boot
usb_boot
header_boot
pins_boot

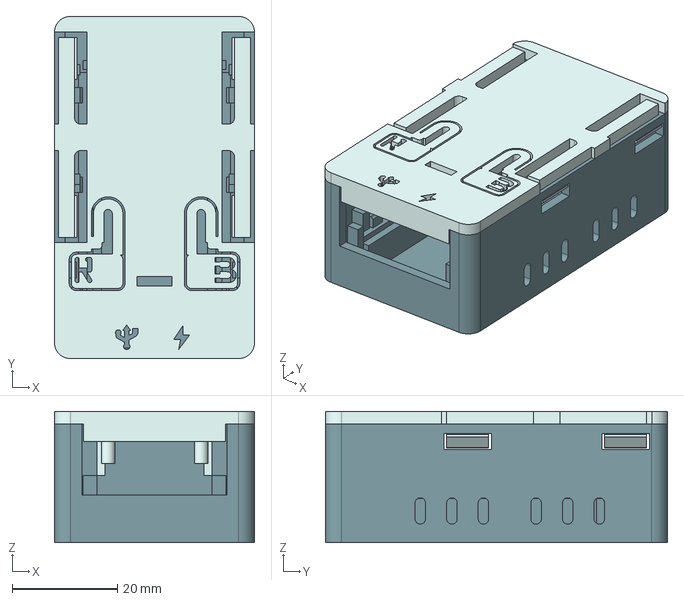
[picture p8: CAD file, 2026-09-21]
stls/case.step
38.0 x 65.0 x 24.9 mm
base
lid

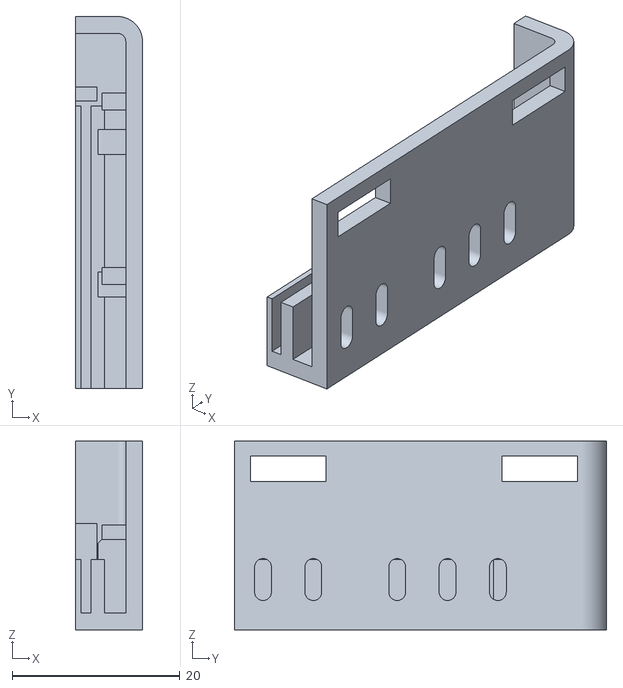
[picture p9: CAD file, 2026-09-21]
stls/snap-test-base.stl
8.00 x 44.4 x 22.5

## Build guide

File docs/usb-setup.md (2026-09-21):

# Browser and CLI setup over USB

The static setup page installs firmware and sends configuration directly to the ESP32 through its UART/programming USB port. It does not need Wi-Fi, a companion application, a text document, or a keyboard already connected to the switcher. Use a computer with desktop Chrome or Edge, a mouse/trackpad, and a USB data cable. Initial host Bluetooth pairing still takes place in each computer's operating-system Bluetooth settings.

## First-time setup

1. Open the hosted setup page (or the local server below). Connect the Freenove ESP32-S3 **16 MB flash / 8 MB PSRAM** UART port, leaving the native USB host port for wired input devices.
2. If needed, click **Install firmware** beside **Connect board**, choose a version in the modal, then click **Install selected version**. Install remains available while setup is connected: it asks permission, cancels pending setup work, releases the USB port, and opens the installer using that same port. Declining leaves setup connected. The packaged build includes experimental BLE keyboard/relative-trackpad input. Leave erase disabled on updates to preserve settings.
3. Close the install dialog, then choose **Connect board** and select its serial port. Only one browser tab or serial monitor can own the port at a time. Opening it may reset the ESP32.
4. Put the wireless keyboard in Bluetooth pairing mode. Click **Scan for keyboards**, then its name. For a keyboard passkey, type the displayed code on the wireless keyboard and press Enter. For numeric comparison, check both displays and click **Codes match** only if they agree. Use **Cancel pairing** to reject. Scanning never pairs automatically. Wait for the connected result; accepted means the operation started, not that pairing succeeded.
5. Select a computer slot on the page. In that computer's Bluetooth settings, pair with the displayed switcher name. New destination-computer passkeys appear on the page while it is connected. Repeat for other slots. Default names let you finish setup without typing names.
6. Configure names, left-to-right slot order, shortcuts, and optional seamless switching. Enable works immediately. Shared sensitivity applies to all monitors; calibration is optional. Calibration progress and results appear on the page; serial-started calibration never types feedback into another application or opens the BOOT menu.
7. Disconnect when finished. The board saves settings immediately through the existing NVS settings code. BOOT configuration still works afterward. BLE input reconnect is explicit in this first experiment: use the page, CLI, or BOOT menu after a reboot.

The browser uses [Web Serial](https://developer.chrome.com/docs/capabilities/serial); flashing uses [ESP Web Tools](https://esphome.github.io/esp-web-tools/). Web Serial needs HTTPS or localhost. The installer component is pinned to ESP Web Tools 10.1.0 and loaded from unpkg; normal configuration uses this site's own JavaScript. Firmware must match this board's memory layout, not just the ESP32-S3 chip family.

## Build / serve / publish

```sh
pio run -e esp32s3_ble_input
python3 scripts/package-web.py --version YOUR_VERSION
python3 -m http.server 8765 --bind 127.0.0.1 --directory artifacts/web-setup
```

Open `http://localhost:8765`. The packager copies the webpage plus separate bootloader, partition, OTA-boot selection, and application images. It validates image sizes and NVS/application offsets, and does not include an image spanning the NVS partition. Flashing resets OTA boot selection to app0. Do not select a full erase if you want to retain pairings/calibration. It does not copy the gap-filled factory image over saved settings.

For GitHub Pages, select **Settings → Pages → Source: GitHub Actions**, then manually run **Browser setup installer**. The workflow builds and packages the BLE input firmware and deploys the page. It does not publish on every push. This repository change alone neither enables Pages nor publishes a URL. Treat the published firmware as experimental until tested with real keyboards and host computers.

## CLI

```sh
python3 -m venv .venv-cli
.venv-cli/bin/pip install -r cli/requirements.txt
.venv-cli/bin/python cli/hid-switcher.py --port /dev/cu.YOUR_UART status
.venv-cli/bin/python cli/hid-switcher.py --port /dev/cu.YOUR_UART shell
```

The interactive shell keeps one serial connection open, avoiding repeated UART-open resets. Enter one JSON command per prompt:

```json
{"op":"input","command":"scan"}
{"op":"input-status"}
{"op":"input","command":"connect 1"}
{"op":"input-status"}
{"op":"select","slot":0}
{"op":"name","name":"Desk Switcher"}
```

Wait for the scan to finish before selecting a result. `input-status` displays the pairing passkey and result. One-shot examples:

```sh
.venv-cli/bin/python cli/hid-switcher.py --port /dev/cu.YOUR_UART select '{"slot":1}'
.venv-cli/bin/python cli/hid-switcher.py --port /dev/cu.YOUR_UART --watch input-status
```

The original UART `1`/`2`/`3`, `?`, `u`, `v` and `b ...` commands remain available. Do not mix clients while a serial operation is pending.

## Protocol v1

115200 baud, newline-delimited UTF-8. Requests begin with `@HID1 `, followed by a JSON object with unsigned integer `id` and string `op`. Responses use the same prefix and echo `id`, `ok`, and either `result` or `error`. Ignore unrelated diagnostic lines. Requests are bounded at 2048 characters after `@`; overlong or frames taking more than three seconds are discarded through the next newline. Clients send one request at a time and must not automatically retry writes after a timeout: query status first.

```text
@HID1 {"id":1,"op":"status"}
@HID1 {"id":1,"ok":true,"result":{...}}
```

Slot/action/field indices in JSON are **zero based**; scan-result numbers are **one based**. Changes share the BOOT menu's existing validation, storage and release barriers. Mutations are rejected while the BOOT menu or incompatible calibration/recording flow owns configuration.

| Operation | Arguments / behavior |
| --- | --- |
| `status` | Capabilities, name, slots, settings generation, selected slot, shortcuts, calibration progress/result |
| `input-status` | Availability, busy state, last status/passkey, numbered devices, revision |
| `input` | `command`: `scan`, `connect N`, `reconnect`, `disconnect`, `forget`, or `status`; acknowledgement means queued |
| `input-cancel` | Cancel pending input scan/connection |
| `select` | `slot`: 0–2; selects forwarding/pairing slot |
| `forget` | `slot`: 0–2 and `confirm`: true; forget that computer |
| `name` | `name`: Bluetooth device name, existing 29-byte validation |
| `slots` | `generation` from status, `order`: permutation of [0,1,2], `names`: three names in new order, each up to 32 bytes |
| `edge` | `value`: existing validated edge-distance setting |
| `monitor-layout` | `generation` from status `monitor_layout`, `active` boolean, three `screens` with integer `x`, `y`, `width`, `height` and boolean `enabled`, `estimated`; saves absolute-mode monitor geometry |
| `pointer-speed` | `value`: shared sensitivity percentage, 1–1600 (100 = one configured desktop pixel per count) |
| `pointer-probe` | Diagnostic only: `x`, `y` normalized 0–32767; sends a button-free absolute position on the selected connected computer, requiring seamless mode and released input |
| `pointer` | Legacy stored per-slot percentages (`slot`, `field`, `value`); retained for older firmware, not used by shared-speed motion. Use `pointer-speed` for current motion. |
| `seamless` | `enabled`: boolean; takes effect without calibration |
| `calibration-start` | `mask`: slot bitmask 1–7, `enable`: enable seamless after successful capture; serial feedback only |
| `calibration-cancel` | Cancel and return to the original slot |
| `shortcuts` | Read bindings |
| `shortcut-record` | `action`: 0 cycle / 1 next / 2 previous / 3 slot; optional `kind`: 1 keyboard / 2 mouse (omitted accepts either); returns session `token` |
| `shortcut-status`, `shortcut-save`, `shortcut-cancel` | `token` from recording; poll until ready, then save explicitly |
| `shortcut-clear` | `action`, `kind`: 1 keyboard / 2 mouse |
| `shortcuts-reset` | Restore defaults |

Recording suppresses forwarding while waiting and capturing. On release, capture ends and forwarding resumes. In the web shortcut table, the pencil records that cell’s input type and saves automatically on release; × removes an existing binding or cancels active recording. Keyboard chords finish after all keys and modifiers are released. The BOOT menu and CLI retain their explicit save flow. A dropped browser session does not erase settings; pending recordings/calibration retain their existing expiration timers. Explicit page Disconnect cancels its pending work. A bare USB unplug is not a configuration command.

## Verification

Host parser/menu tests: `sh scripts/test-host.sh`. Browser transport tests: `node --test tests/web-serial.mjs`. CLI tests: `python3 tests/serial-cli.py`. Browser flow test: serve the packaged site, install Playwright outside the firmware tree, then run `NODE_PATH=PATH_TO_NODE_MODULES node tests/web-setup-browser.cjs`. This uses simulated USB responses and checks 320/390/430/1440 widths; it does not flash hardware or prove physical pairing/latency.

`input-status` also returns `ready`, `saved`, `device`, `saved_name`, `state`, and a `pairing` object (`kind`, `active`, `id`, `code`, `seconds_left`). `input-confirm` takes the displayed `attempt` ID and numeric `code`; expired or mismatched prompts are rejected. UART `b confirm XXXXXX` remains available.

## Page organization and version history

- **Connect / Firmware** connects over USB and reports the installed application version/build. Use the Install firmware button to open a modal and choose any retained package, including an older build. Selection changes the ESP Web Tools manifest; installation remains explicit.
- **Input Devices** lists USB inputs grouped by physical USB address and VID/PID, plus the connected or saved BLE input. USB labels use reported HID capabilities rather than invented product names. **Add BLE device** opens a modal for scanning, selection, pairing and results. Closing it or pressing Escape cancels pending BLE setup, but keeps a completed connection.
- **Outputs** retains the computer-slot controls. Switching and shortcuts remain below.

The packager retains versioned binaries and `firmware/versions.json` in its output directory. Older entries are real retained images, not Git tags without binaries. Repackaging the same version/image does not add duplicates. The Pages workflow restores its previous `web-setup-history` artifact before packaging and uploads the accumulated catalog with 90-day artifact retention. If no prior artifact remains, a fresh deployment contains only the new package; preserve a copy of the site for longer-term archival. No public deployment is implied by a local package.

For an update or downgrade, leave the installer erase option unchecked. NVS stays intact, but compatibility with settings from newer firmware depends on the selected version.

Screen resolution is edited inside the arrangement: click the pencil beside a screen's dimensions, enter width and height, and choose Done. Drag screens to position them, then save the arrangement. Calibration supplies estimated starting proportions for an unsaved arrangement; it does not measure pixel resolution or replace saved dimensions. Arrange in a row resets visual positions.

The selected screen's speed adjustment remains visible (25–400%, default 100%). Effective speed is shared speed × screen percentage / 100 on both axes; geometry and edge alignment stay unchanged. Existing arrangements migrate with all adjustments at 100%. Calibration and edge travel remain directly accessible.

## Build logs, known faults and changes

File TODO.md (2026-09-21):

# Follow-up work

- Automatic fallback when the selected computer disconnects, with an explicit user preference.
- Investigate controller-completion latency spikes during simultaneous typing and mouse movement; distinguish them from end-to-end latency.
- Test three simultaneous hosts and Windows/Linux reconnection behavior.
- Explore vendor HID/HID++ passthrough so mouse configuration software can communicate with the original device. Advertising vendor IDs alone is insufficient.
- Investigate mouse hardware settings only after detecting supported vendor features; do not assume Motion Sync or configurable polling rate.
- Configuration backup/restore and additional LED feedback; per-host axis tuning and calibration are implemented.
- Extend the validated absolute mouse layout with horizontal pan and buttons 6–8 without regressing macOS dragging.
- Validate physical USB hub unplug/replug recovery; successful startup and software recovery are not sufficient proof.
- Additional host keyboard layouts and Unicode names in the device menu.

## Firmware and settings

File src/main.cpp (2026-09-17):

#include "Application.h"
#include "Board.h"
#include <Arduino.h>

namespace {
Application application;
}

void setup() {
  Serial.setTxBufferSize(2048);
  Serial.begin(Board::serialBaud);
  // Preserve the proven startup interval before the USB host resets the hub.
  // The hub and downstream devices can share the board's power supply.
  delay(1000);
  application.begin();
}

void loop() {
  application.tick();
  delay(1);
}

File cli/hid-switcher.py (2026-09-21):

#!/usr/bin/env python3
"""USB configuration client. Slot indices are zero based. No automatic writes/retries."""
import argparse
import json
import sys
import time


def request(port, sequence, command):
    payload = dict(command, id=sequence)
    wire = ('@HID1 ' + json.dumps(payload, separators=(',', ':')) + '\n').encode()
    if len(wire) > 2049:
        raise ValueError('Request exceeds 2048 bytes')
    port.write(wire)
    deadline = time.monotonic() + 6
    buffered = b''
    discarding = False
    while time.monotonic() < deadline:
        chunk = port.read_until(b'\n', 32768)
        if len(buffered) + len(chunk) > 32768:
            buffered = b''; discarding = True
        if not discarding:
            buffered += chunk
        if not chunk.endswith(b'\n'):
            continue
        if discarding:
            discarding = False; continue
        line = buffered.decode('utf-8', errors='replace').strip()
        buffered = b''
        if line.startswith('[BLE computer pairing]'):
            print(line, file=sys.stderr)
        if not line.startswith('@HID1 '):
            continue
        try:
            response = json.loads(line[6:])
        except json.JSONDecodeError:
            continue
        if response.get('id') == sequence:
            return response
    raise TimeoutError('No reply. Check UART port/firmware. Query status before retrying a change.')


def main():
    parser = argparse.ArgumentParser(description=__doc__)
    parser.add_argument('--port', required=True)
    parser.add_argument('--watch', action='store_true', help='Poll status or input-status once a second')
    parser.add_argument('op', nargs='?', default='status', help='Operation; shell keeps one port open for interactive JSON commands')
    parser.add_argument('args', nargs='?', default='{}', help='JSON object of arguments')
    args = parser.parse_args()
    if args.watch and args.op not in ('status', 'input-status', 'shortcut-status'):
        parser.error('--watch is only for read operations')
    import serial
    import secrets
    port = serial.Serial(port=None, baudrate=115200, timeout=0.5, write_timeout=2)
    port.dtr = False; port.rts = False; port.port = args.port
    with port:
        time.sleep(2)  # UART bridges can reset the board when opened.
        sequence = secrets.randbelow(0x7fffffff)
        while True:
            if args.op == 'shell':
                try:
                    raw = input('hid> ')
                except EOFError:
                    break
                if raw in ('exit', 'quit'):
                    break
                try:
                    command = json.loads(raw)
                except json.JSONDecodeError as error:
                    print(error, file=sys.stderr); continue
            else:
                command = json.loads(args.args)
                if not isinstance(command, dict):
                    raise ValueError('Arguments must be a JSON object')
                command['op'] = args.op
            if not isinstance(command, dict) or not isinstance(command.get('op'), str):
                raise ValueError('Command must be an object with an op string')
            sequence += 1
            result = request(port, sequence, command)
            print(json.dumps(result, indent=2))
            if args.watch:
                time.sleep(1)
            elif args.op != 'shell':
                return 0 if result.get('ok') else 1
    return 0


if __name__ == '__main__':
    try:
        sys.exit(main())
    except KeyboardInterrupt:
        sys.exit(130)
    except Exception as error:
        print(str(error), file=sys.stderr)
        sys.exit(1)

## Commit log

2026-09-15 fix(usb): resolve HID transfers by device and endpoint
    [BLEManager.cpp, BLEManager.h, main.cpp]
2026-09-15 feat(hid): route keyboard and mouse across persistent BLE hosts
    [moonlander_ota.csv]
2026-09-15 feat(diagnostics): track Bluetooth controller completion timing
2026-09-15 ci: build and attach macOS CLI release packages
2026-09-15 docs: document HID Switcher setup and validation
2026-09-16 feat(shortcuts): record keyboard and mouse switching bindings
    [BLEManager.cpp, BLEManager.h]
2026-09-16 docs: describe current setup and shortcuts in simplified English
2026-09-16 feat(config): replace CLI and Wi-Fi with an on-device text menu
    [BLEManager.cpp, BLEManager.h]
2026-09-16 feat(pairing): forget one computer from the device menu
2026-09-16 refactor: own USB lifecycle and input dispatch in HID Switcher
2026-09-16 docs: use HID Switcher branding and simplify dependency credits
    [hid_switcher_partitions.csv]
2026-09-16 docs: add configuration GIFs and HID Switcher artwork
2026-09-16 docs: describe switching and compatibility in plain language
2026-09-17 feat: add BLE companion for pointer-edge computer switching
2026-09-17 fix(usb): restore startup settling time before hub enumeration
    [main.cpp]
2026-09-17 fix(usb): keep active input when extra interfaces cannot open
    [UsbHost.cpp]
2026-09-17 fix(edge): switch immediately with optional destination cursor placement
    [BleHid.cpp]
2026-09-17 fix(edge): switch on outward motion without cursor repositioning
    [BleHid.cpp]
2026-09-17 fix(mac): keep companion timers running while the menu is open
2026-09-17 fix(edge): follow linear slot order without wrapping
2026-09-17 feat(edge): configure and persist movement threshold in device menu
2026-09-20 feat(hid): add calibrated edge switching with isolated mouse services
    Keep absolute gestures on the NanoKVM-style mouse and use a separate BLE HID service for relative mode and per-slot calibration. Restore origin-host feedback and menu flow, preserve settings, and include USB recovery fixes and diagnostics.
    Document installation, verified two-computer operation, and remaining limits. Host tests, all firmware variants, and partition checks pass.
    [AbsolutePointer.h, Application.cpp, Application.h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]
2026-09-20 feat(case): add measured Freenove enclosure and printable assets
    Include the parametric case, reinforced internal catches, button actuators, ventilation, cut-through labels, and printing instructions. Retain CAD and slicer validation records; exported STL hashes match the recorded slicing inputs.
    [base.stl, board-reference.step, case.step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]
2026-09-20 docs: compare companion-free and companion edge switching
2026-09-21 feat: add BLE input setup and monitor-aware switching
2026-09-21 ci: update PlatformIO for ESP32 build
2026-09-21 docs: add current setup and folded quick start
2026-09-21 ci: pin pioarduino and expand setup handout
2026-09-21 docs: print hosted setup URL
2026-09-21 docs: prevent quick start print clipping
